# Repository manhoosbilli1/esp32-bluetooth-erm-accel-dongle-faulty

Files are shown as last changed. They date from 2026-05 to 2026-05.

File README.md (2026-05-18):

# daronjli_dongle_final_manufactured

ESP32 Bluetooth dongle with ERM haptic motor and accelerometer - FAULTY: wrong ORing circuit, used NMOS instead of PMOS

## At a Glance

- **Status**: Manufactured
- **Board size**: 23.26 x 28.39 mm
- **Layers**: 4
- **Components**: 56
- **Key ICs**:
  - U1: MCP73831-2-MC
  - U2: CP2102N-Axx-xQFN24
  - U3: LIS3DH
  - U4: DRV2605LDGS
  - U5: SY8089AAAC
  - U6: ESP32-WROOM-32E

## Schematic

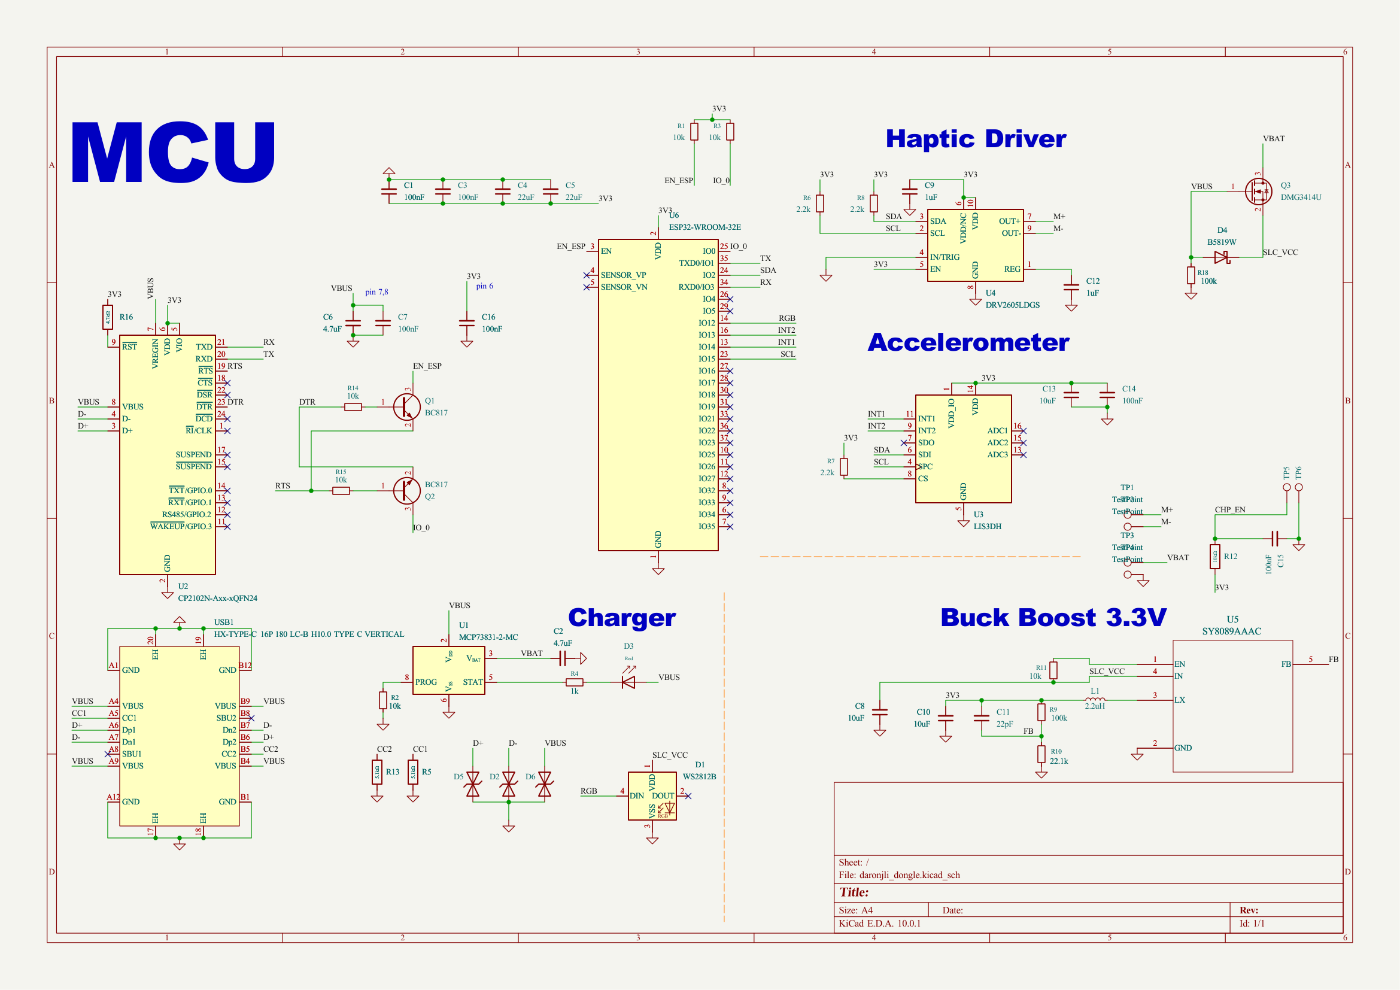
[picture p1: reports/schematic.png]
Schematic


Full PDF: [reports/schematic.pdf](reports/schematic.pdf)

## Component Roles

- **ESP32-WROVER-E** - main MCU with Bluetooth; firmware runs here
- **DRV2605LDGS** - haptic motor driver (configured for ERM motor) for tactile feedback
- **LIS3DH** - 3-axis accelerometer for orientation / motion detection
- **CP2102N** - USB-to-UART bridge for firmware programming
- **TPS63020** - buck-boost regulator (stable 3.3 V from a swinging LiPo)
- **MCP73871** - LiPo charger with PowerPath (USB vs battery source switching)
- **MAX17048** - I2C fuel gauge for battery percentage

## Known fault

This manufactured revision has a **broken OR-ing / PowerPath circuit**: the design used an N-channel MOSFET where a P-channel MOSFET was required. Result: source switching between USB and battery does not work correctly. Use the active [daronjli-dongle](https://github.com/manhoosbilli1/daronjli-dongle) repo for the fix.

## PCB

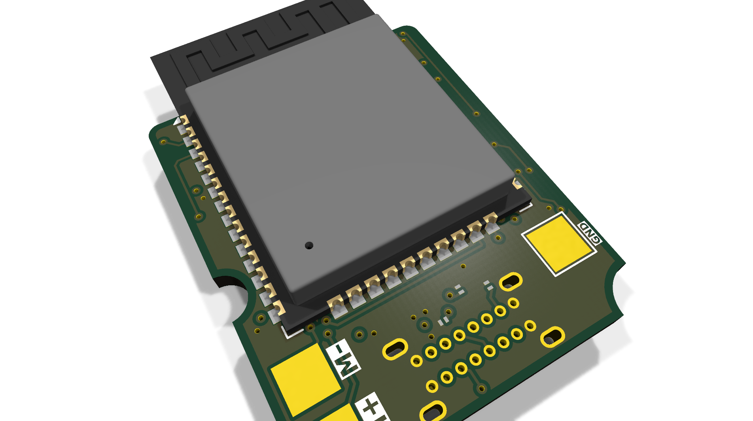
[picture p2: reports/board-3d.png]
3D top


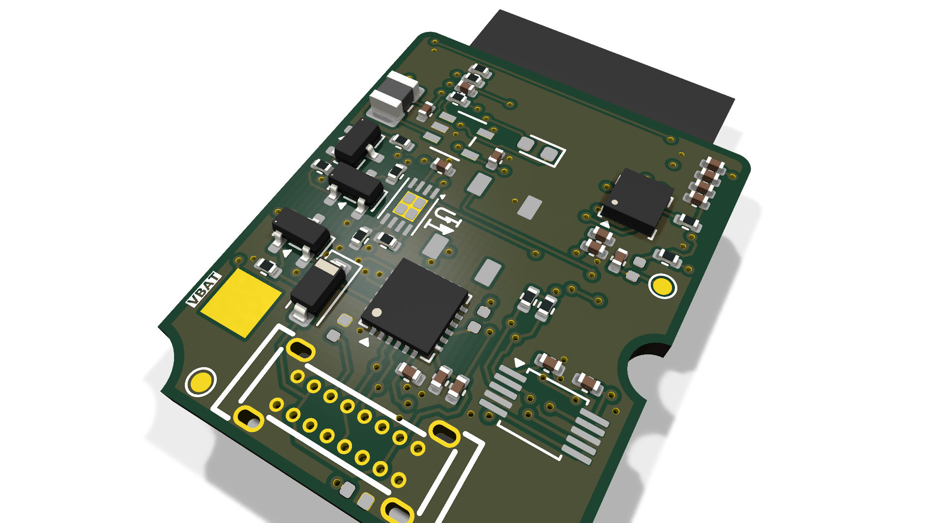
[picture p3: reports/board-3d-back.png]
3D bottom


**Top copper**

PCB top

**Bottom copper**

PCB bottom

## Bill of Materials

| Refs | Value | Footprint | Qty | MPN | LCSC |
|---|---|---|----:|-----|---|
| C1,C3,C7,C14-C16 | 100nF | Capacitor_SMD:C_0402_1005Metric | 6 |  |  |
| C2,C6 | 4.7uF | Capacitor_SMD:C_0402_1005Metric | 2 |  | [C307423](https://www.lcsc.com/product-detail/_C307423.html) |
| C4,C5 | 22uF | Capacitor_SMD:C_0402_1005Metric | 2 |  |  |
| C8,C10,C13 | 10uF | Capacitor_SMD:C_0402_1005Metric | 3 |  |  |
| C9,C12 | 1uF | Capacitor_SMD:C_0402_1005Metric | 2 |  |  |
| C11 | 22pF | Capacitor_SMD:C_0402_1005Metric | 1 |  |  |
| D1 | WS2812B | PCM_JLCPCB:LED_WS2812B_PLCC4_5.0x5.0mm_P3.2mm | 1 |  | [C22461793](https://www.lcsc.com/product-detail/_C22461793.html) |
| D2,D5,D6 | H5VL06B | PCM_JLCPCB:D_DFN0603-2L | 3 |  | [C7420373](https://www.lcsc.com/product-detail/_C7420373.html) |
| D3 | Red | PCM_JLCPCB:D_0603 | 1 |  | [C2286](https://www.lcsc.com/product-detail/_C2286.html) |
| D4 | B5819W | Diode_SMD:D_SOD-123 | 1 |  |  |
| L1 | 2.2uH | Inductor_SMD:L_1008_2520Metric_Pad1.43x2.20mm_HandSolder | 1 |  |  |
| Q1,Q2 | BC817 | Package_TO_SOT_SMD:SOT-23 | 2 |  |  |
| Q3 | DMG3414U | Package_TO_SOT_SMD:SOT-23 | 1 |  |  |
| R1-R3,R11,R14,R15 | 10k | Resistor_SMD:R_0402_1005Metric | 6 |  | [C60490](https://www.lcsc.com/product-detail/_C60490.html) |
| R4 | 1k | Resistor_SMD:R_0402_1005Metric | 1 |  | [C106235](https://www.lcsc.com/product-detail/_C106235.html) |
| R5,R13 | 5.1kΩ | PCM_JLCPCB:R_0402 | 2 |  | [C25905](https://www.lcsc.com/product-detail/_C25905.html) |
| R6-R8 | 2.2k | Resistor_SMD:R_0402_1005Metric | 3 |  |  |
| R9,R18 | 100k | Resistor_SMD:R_0402_1005Metric | 2 |  |  |
| R10 | 22.1k | Resistor_SMD:R_0402_1005Metric | 1 |  | [C43473](https://www.lcsc.com/product-detail/_C43473.html) |
| R12 | 10kΩ | PCM_JLCPCB:R_0402 | 1 |  | [C25744](https://www.lcsc.com/product-detail/_C25744.html) |
| R16 | 4.7kΩ | PCM_JLCPCB:R_0402 | 1 |  | [C25900](https://www.lcsc.com/product-detail/_C25900.html) |
| TP1-TP4 | TestPoint | TestPoint:TestPoint_Pad_3.0x3.0mm | 4 |  |  |
| TP5,TP6 | TestPoint | TestPoint:TestPoint_Pad_D1.0mm | 2 |  |  |
| U1 | MCP73831-2-MC | Package_DFN_QFN:DFN-8-1EP_3x2mm_P0.5mm_EP1.7x1.4mm | 1 |  | [C150772](https://www.lcsc.com/product-detail/_C150772.html) |
| U2 | CP2102N-Axx-xQFN24 | Package_DFN_QFN:QFN-24-1EP_4x4mm_P0.5mm_EP2.6x2.6mm | 1 |  | [C969151](https://www.lcsc.com/product-detail/_C969151.html) |
| U3 | LIS3DH | Package_LGA:LGA-16_3x3mm_P0.5mm_LayoutBorder3x5y | 1 |  |  |
| U4 | DRV2605LDGS | Package_SO:VSSOP-10_3x3mm_P0.5mm | 1 |  |  |
| U5 | SY8089AAAC | footprints:SY8089AAAC_SGY | 1 |  |  |
| U6 | ESP32-WROOM-32E | RF_Module:ESP32-WROOM-32D | 1 |  | [C701343](https://www.lcsc.com/product-detail/_C701343.html) |
| USB1 | HX-TYPE-C 16P 180 LC-B H10.0 TYPE C VERTICAL | :USB-C-TH_HX-TYPE-C-16P-180-LC-BH10.0-TYPE-C-VERTICAL | 1 |  |  |

_17 of 30 line items don't have an LCSC code in the schematic - search [LCSC](https://www.lcsc.com/) or [JLC parts search](https://jlcsearch.tscircuit.com/) by MPN or footprint when sourcing._

## Files

- `daronjli_dongle.kicad_pro` - KiCad project
- `daronjli_dongle.kicad_sch` - schematic source
- `daronjli_dongle.kicad_pcb` - PCB layout source
- `reports/schematic.pdf` - full schematic (printable)
- `reports/bom.csv` - bill of materials
- `reports/pcb-top.svg`, `reports/pcb-bottom.svg` - copper artwork
- `reports/board-stats.json` - KiCad-generated board statistics

---

_Renders and metadata auto-generated by `Backup-KiCadProject.ps1` using KiCad 10.0._

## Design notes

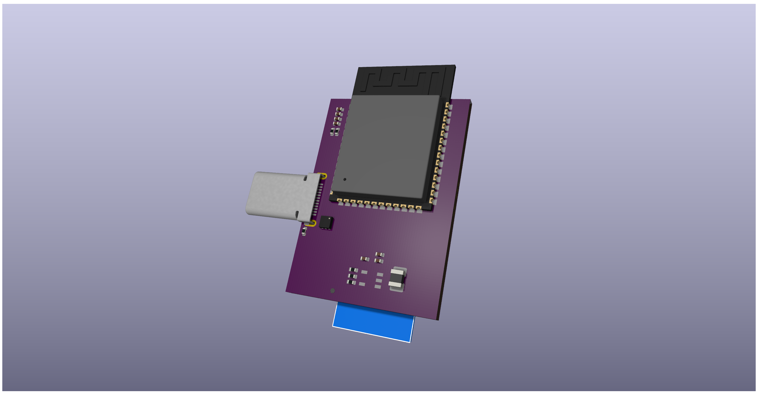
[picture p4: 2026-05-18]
daronjli_dongle.png

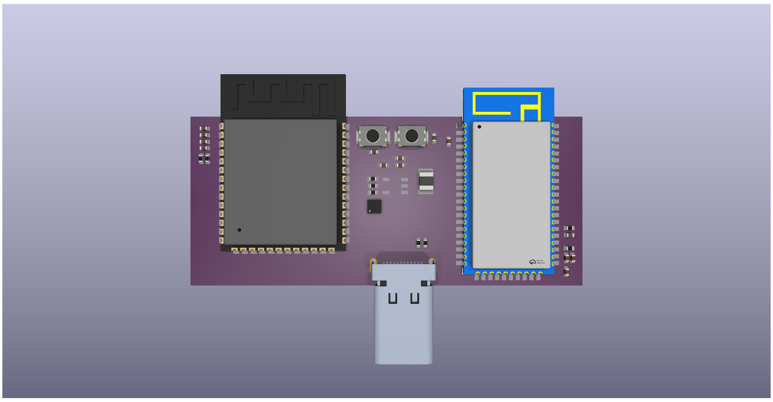
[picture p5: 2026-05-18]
daronjli_dongle_draft1_placement.png

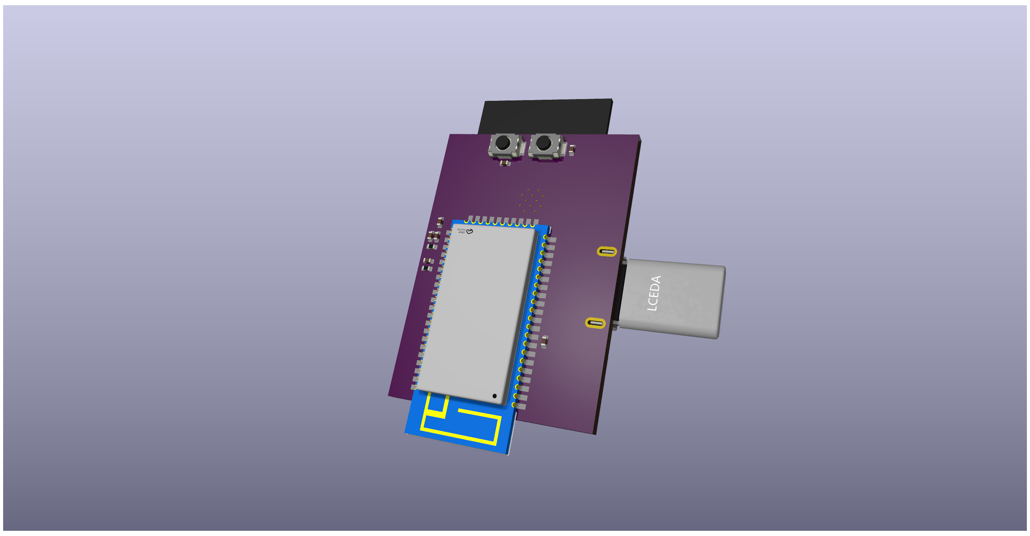
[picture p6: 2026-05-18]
daronjli_dongle_back.png

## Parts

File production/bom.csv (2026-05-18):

Designator | Footprint | Quantity | Value | LCSC Part #
C1, C14, C15, C16, C3, C7 | 0402 | 6 | 100nF
C10, C13, C8 | 0402 | 3 | 10uF
C11 | 0402 | 1 | 22pF
C12, C9 | 0402 | 2 | 1uF
C2, C6 | 0402 | 2 | 4.7uF | C307423
C4, C5 | 0402 | 2 | 22uF
D1 | LED_WS2812B_PLCC4_5.0x5.0mm_P3.2mm | 1 | WS2812B | C22461793
D2, D5, D6 | D_DFN0603-2L | 3 | H5VL06B | C7420373
D3 | D_0603 | 1 | Red | C2286
D4 | D_SOD-123 | 1 | B5819W
L1 | 1008 | 1 | 2.2uH
Q1, Q2 | SOT-23 | 2 | BC817
Q3 | SOT-23 | 1 | DMG3414U
R1, R11, R14, R15, R3 | 0402 | 5 | 10k
R10 | 0402 | 1 | 22.1k | C43473
R12 | R_0402 | 1 | 10kΩ | C25744
R13, R5 | R_0402 | 2 | 5.1kΩ | C25905
R16 | R_0402 | 1 | 4.7kΩ | C25900
R18, R9 | 0402 | 2 | 100k
R2 | 0402 | 1 | 10k | C60490
R4 | 0402 | 1 | 1k | C106235
R6, R7, R8 | 0402 | 3 | 2.2k
TP1, TP2, TP3, TP4 | TestPoint_Pad_3.0x3.0mm | 4 | TestPoint
TP5, TP6 | TestPoint_Pad_D1.0mm | 2 | TestPoint
U1 | DFN-8-1EP_3x2mm_P0.5mm_EP1.7x1.4mm | 1 | MCP73831-2-MC | C150772
U2 | QFN-24-1EP_4x4mm_P0.5mm_EP2.6x2.6mm | 1 | CP2102N-Axx-xQFN24 | C969151
U3 | LGA-16_3x3mm_P0.5mm_LayoutBorder3x5y | 1 | LIS3DH
U4 | VSSOP-10_3x3mm_P0.5mm | 1 | DRV2605LDGS
U5 | SY8089AAAC_SGY | 1 | SY8089AAAC
U6 | ESP32-WROOM-32D | 1 | ESP32-WROOM-32E | C701343
USB1 | USB-C-TH_HX-TYPE-C-16P-180-LC-BH10.0-TYPE-C-VERTICAL | 1 | HX-TYPE-C 16P 180 LC-B H10.0 TYPE C VERTICAL | C49261584

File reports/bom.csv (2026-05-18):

Refs | Value | Footprint | Qty | Description | Mfr | MPN | LCSC
C1,C3,C7,C14-C16 | 100nF | Capacitor_SMD:C_0402_1005Metric | 6 | Unpolarized capacitor, small symbol
C2,C6 | 4.7uF | Capacitor_SMD:C_0402_1005Metric | 2 | Unpolarized capacitor, small symbol |  |  | C307423
C4,C5 | 22uF | Capacitor_SMD:C_0402_1005Metric | 2 | Unpolarized capacitor, small symbol
C8,C10,C13 | 10uF | Capacitor_SMD:C_0402_1005Metric | 3 | Unpolarized capacitor, small symbol
C9,C12 | 1uF | Capacitor_SMD:C_0402_1005Metric | 2 | Unpolarized capacitor, small symbol
C11 | 22pF | Capacitor_SMD:C_0402_1005Metric | 1 | Unpolarized capacitor, small symbol
D1 | WS2812B | PCM_JLCPCB:LED_WS2812B_PLCC4_5.0x5.0mm_P3.2mm | 1 | RGB LED with integrated controller |  |  | C22461793
D2,D5,D6 | H5VL06B | PCM_JLCPCB:D_DFN0603-2L | 3 | 8A 10V 80W 5.6V Bidirectional 5V DFN0603-2L ESD and Surge Protection (TVS/ESD) ROHS | hongjiacheng |  | C7420373
D3 | Red | PCM_JLCPCB:D_0603 | 1 | -40°C~+85°C Red 0603 LED Indication - Discrete ROHS | Hubei KENTO Elec |  | C2286
D4 | B5819W | Diode_SMD:D_SOD-123 | 1 | Schottky diode
L1 | 2.2uH | Inductor_SMD:L_1008_2520Metric_Pad1.43x2.20mm_HandSolder | 1 | Inductor, small symbol
Q1,Q2 | BC817 | Package_TO_SOT_SMD:SOT-23 | 2 | 0.8A Ic, 45V Vce, NPN Transistor, SOT-23
Q3 | DMG3414U | Package_TO_SOT_SMD:SOT-23 | 1 | 4.2A Id, 20V Vds, N-Channel MOSFET, SOT-23
R1-R3,R11,R14,R15 | 10k | Resistor_SMD:R_0402_1005Metric | 6 | Resistor, small symbol |  |  | C60490
R4 | 1k | Resistor_SMD:R_0402_1005Metric | 1 | Resistor, small symbol |  |  | C106235
R5,R13 | 5.1kΩ | PCM_JLCPCB:R_0402 | 2 | 62.5mW Thick Film Resistors 50V ±100ppm/°C ±1% 5.1kΩ 0402 Chip Resistor - Surface Mount ROHS | UNI-ROYAL(Uniroyal Elec) |  | C25905
R6-R8 | 2.2k | Resistor_SMD:R_0402_1005Metric | 3 | Resistor, small symbol
R9,R18 | 100k | Resistor_SMD:R_0402_1005Metric | 2 | Resistor, small symbol
R10 | 22.1k | Resistor_SMD:R_0402_1005Metric | 1 | Resistor, small symbol |  |  | C43473
R12 | 10kΩ | PCM_JLCPCB:R_0402 | 1 | 62.5mW Thick Film Resistors 50V ±100ppm/°C ±1% 10kΩ 0402 Chip Resistor - Surface Mount ROHS | UNI-ROYAL(Uniroyal Elec) |  | C25744
R16 | 4.7kΩ | PCM_JLCPCB:R_0402 | 1 | 62.5mW Thick Film Resistors 50V ±100ppm/°C ±1% 4.7kΩ 0402 Chip Resistor - Surface Mount ROHS | UNI-ROYAL(Uniroyal Elec) |  | C25900
TP1-TP4 | TestPoint | TestPoint:TestPoint_Pad_3.0x3.0mm | 4 | test point
TP5,TP6 | TestPoint | TestPoint:TestPoint_Pad_D1.0mm | 2 | test point
U1 | MCP73831-2-MC | Package_DFN_QFN:DFN-8-1EP_3x2mm_P0.5mm_EP1.7x1.4mm | 1 | Single cell, Li-Ion/Li-Po charge management controller, 4.20V, Tri-State Status Output, in DFN-8 package |  |  | C150772
U2 | CP2102N-Axx-xQFN24 | Package_DFN_QFN:QFN-24-1EP_4x4mm_P0.5mm_EP2.6x2.6mm | 1 | USB to UART master bridge, QFN-24 |  |  | C969151
U3 | LIS3DH | Package_LGA:LGA-16_3x3mm_P0.5mm_LayoutBorder3x5y | 1 | 3-Axis Accelerometer, 2/4/8/16g range, I2C/SPI interface, LGA-16
U4 | DRV2605LDGS | Package_SO:VSSOP-10_3x3mm_P0.5mm | 1 | Haptic driver for LRAs and ERMs with effect library, 2-5.2V, VSSOP-10
U5 | SY8089AAAC | footprints:SY8089AAAC_SGY | 1
U6 | ESP32-WROOM-32E | RF_Module:ESP32-WROOM-32D | 1 | RF Module, ESP32-D0WD-V3 SoC, without PSRAM, Wi-Fi 802.11b/g/n, Bluetooth, BLE, 32-bit, 2.7-3.6V, onboard antenna, SMD |  |  | C701343
USB1 | HX-TYPE-C 16P 180 LC-B H10.0 TYPE C VERTICAL | :USB-C-TH_HX-TYPE-C-16P-180-LC-BH10.0-TYPE-C-VERTICAL | 1

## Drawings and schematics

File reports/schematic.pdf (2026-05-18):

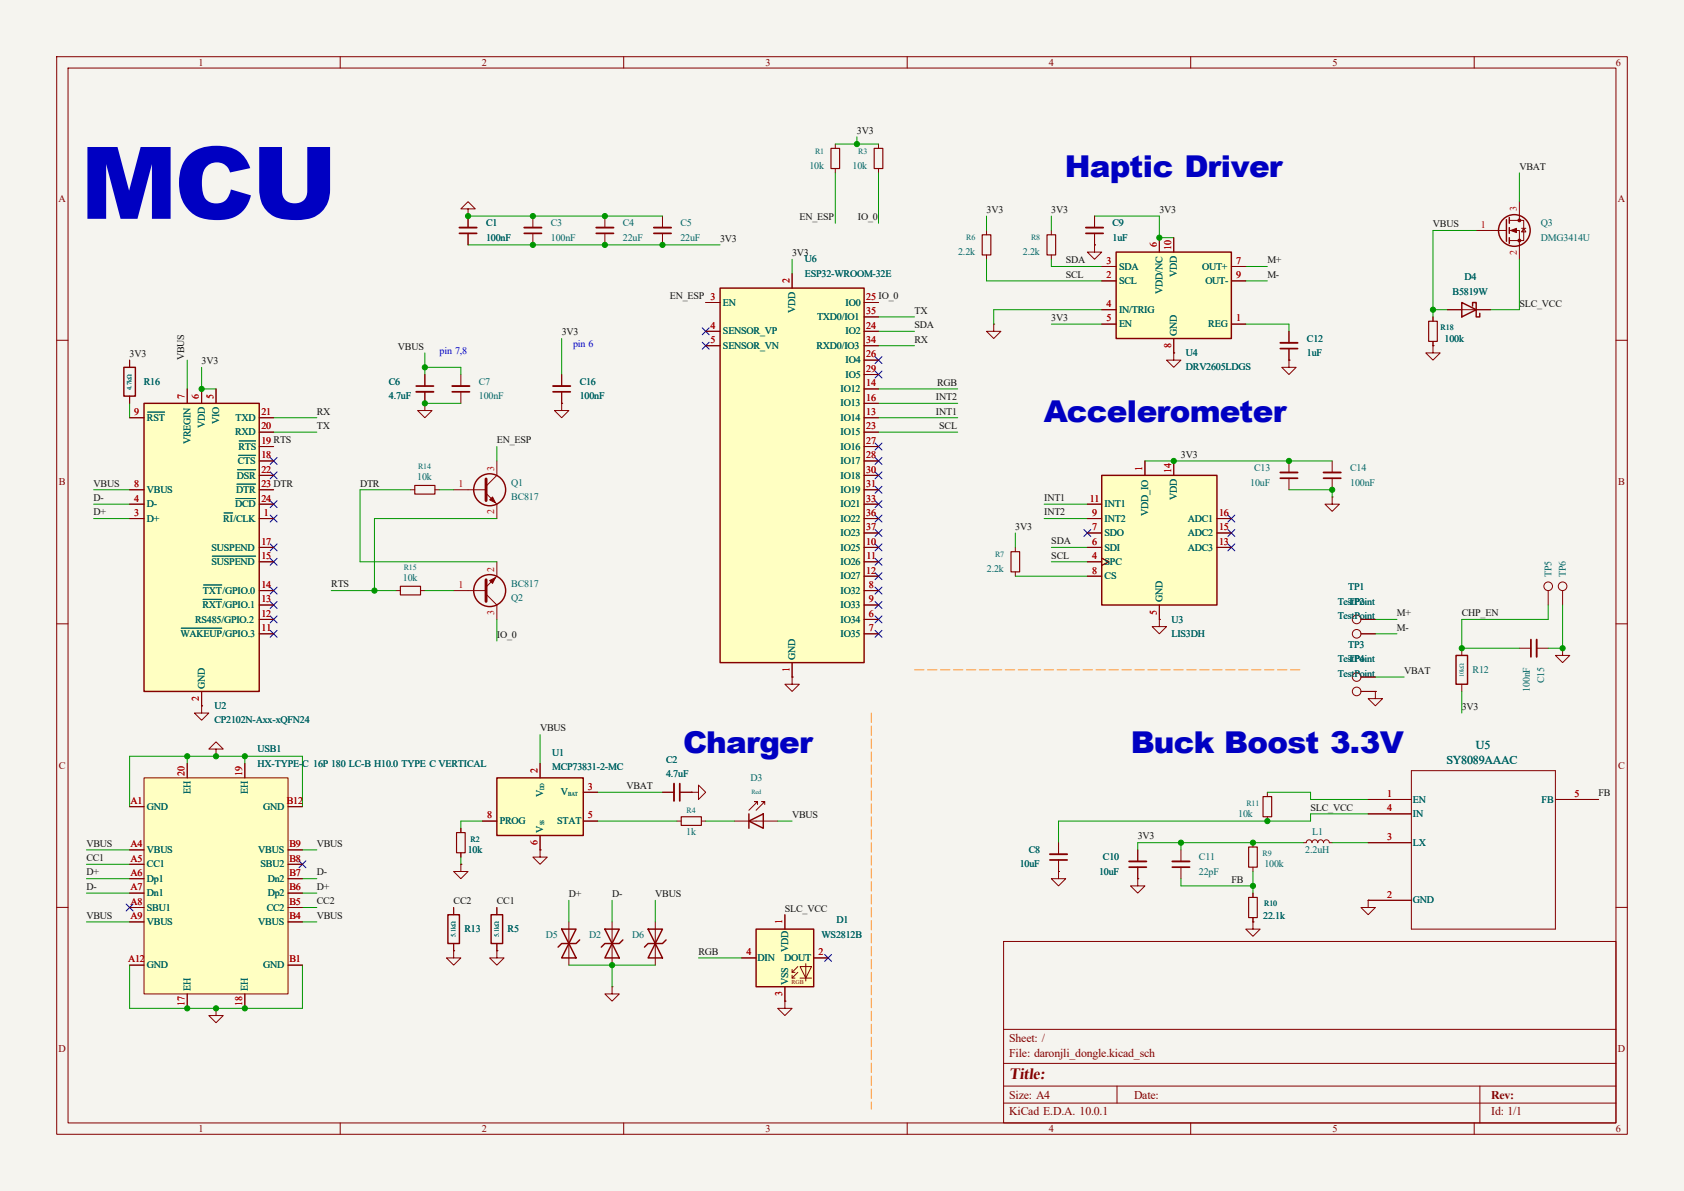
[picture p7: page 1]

8 OUT- VDD 9 10 U4 DRV2605LDGS EH 17 EH 18 EH 19 EH 20 GND A1 VBUS A4 CC1 A5 Dp1 A6 Dn1 A7 SBU1 A8 VBUS A9 GND A12 GND B1 VBUS B4 CC2 B5 Dp2 B6 Dn2 B7 SBU2 B8 VBUS B9 GND B12 USB1 HX-TYPE-C 16P 180 LC-B H10.0 TYPE C VERTICAL R13 5.1kΩ R2 10k R7 2.2k VDD_IO

7 VBUS 8 RST 9 WAKEUP/GPIO.3 11 RS485/GPIO.2 12 RXT/GPIO.1 13 TXT/GPIO.0 14 SUSPEND 15 SUSPEND 17 CTS 18 RTS 19 RXD 20 TXD 21 DSR 22 DTR 23 DCD 24 R16 4.7kΩ D1 WS2812B VDD

7 VBUS 8 RST 9 WAKEUP/GPIO.3 11 RS485/GPIO.2 12 RXT/GPIO.1 13 TXT/GPIO.0 14 SUSPEND 15 SUSPEND 17 CTS 18 RTS 19 RXD 20 TXD 21 DSR 22 DTR 23 DCD 24 U2 CP2102N-Axx-xQFN24 C6

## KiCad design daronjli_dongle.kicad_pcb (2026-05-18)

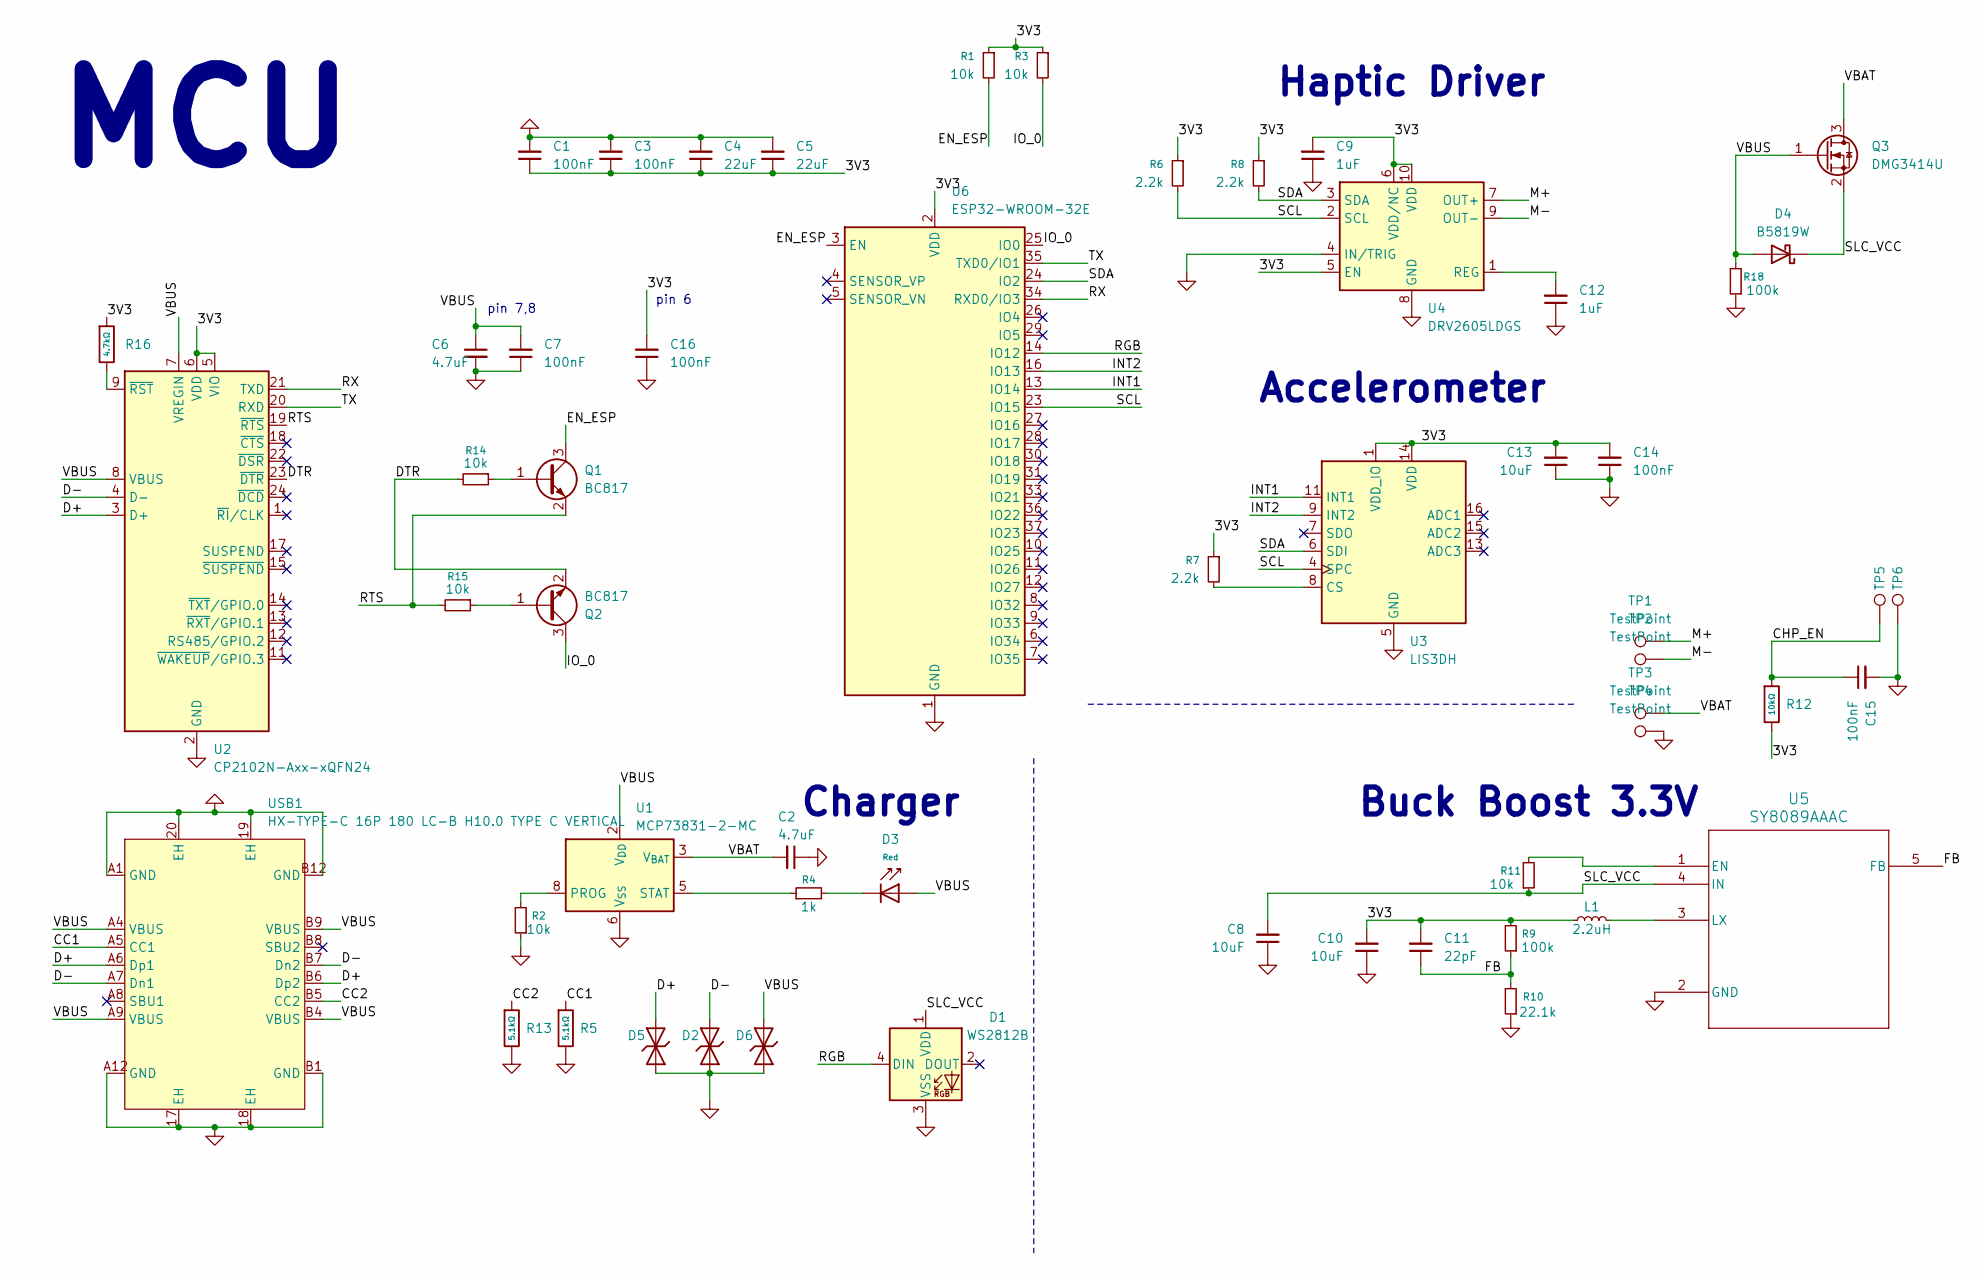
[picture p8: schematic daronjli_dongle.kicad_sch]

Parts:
C1, C3, C7, C14, C15, C16: 100nF; C_0402_1005Metric
C2, C6: 4.7uF; C_0402_1005Metric; LCSC C307423
C4, C5: 22uF; C_0402_1005Metric
C8, C10, C13: 10uF; C_0402_1005Metric
C9, C12: 1uF; C_0402_1005Metric
C11: 22pF; C_0402_1005Metric
D1: WS2812B; LED_WS2812B_PLCC4_5.0x5.0mm_P3.2mm; LCSC C22461793
D2, D5, D6: H5VL06B; D_DFN0603-2L; Clamping Voltage@Ipp 10V; Breakdown Voltage (VBR) 5.6V; Part H5VL06B; LCSC C7420373
D3: Red; D_0603; Part KT-0603R; LCSC C2286
D4: B5819W; D_SOD-123
L1: 2.2uH; L_1008_2520Metric_Pad1.43x2.20mm_HandSolder
Q1, Q2: BC817; SOT-23
Q3: DMG3414U; SOT-23
R1, R3, R11, R14, R15: 10k; R_0402_1005Metric
R2: 10k; R_0402_1005Metric; LCSC C60490
R4: 1k; R_0402_1005Metric; LCSC C106235
R5, R13: 5.1kΩ; R_0402; Overload Voltage (Max) 50V; Tolerance ±1%; Part 0402WGF5101TCE; LCSC C25905
R6, R7, R8: 2.2k; R_0402_1005Metric
R9, R18: 100k; R_0402_1005Metric
R10: 22.1k; R_0402_1005Metric; LCSC C43473
R12: 10kΩ; R_0402; Overload Voltage (Max) 50V; Tolerance ±1%; Part 0402WGF1002TCE; LCSC C25744
R16: 4.7kΩ; R_0402; Overload Voltage (Max) 50V; Tolerance ±1%; Part 0402WGF4701TCE; LCSC C25900
TP1, TP2, TP3, TP4: TestPoint; TestPoint_Pad_3.0x3.0mm
TP5, TP6: TestPoint; TestPoint_Pad_D1.0mm
U1: MCP73831-2-MC; DFN-8-1EP_3x2mm_P0.5mm_EP1.7x1.4mm; LCSC C150772
U2: CP2102N-Axx-xQFN24; QFN-24-1EP_4x4mm_P0.5mm_EP2.6x2.6mm; LCSC C969151
U3: LIS3DH; LGA-16_3x3mm_P0.5mm_LayoutBorder3x5y
U4: DRV2605LDGS; VSSOP-10_3x3mm_P0.5mm
U5: SY8089AAAC; SY8089AAAC_SGY
U6: ESP32-WROOM-32E; ESP32-WROOM-32D; LCSC C701343
USB1: HX-TYPE-C 16P 180 LC-B H10.0 TYPE C VERTICAL; USB-C-TH_HX-TYPE-C-16P-180-LC-BH10.0-TYPE-C-VERTICAL; LCSC Part C49261584

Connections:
/3V3: C1.1, C3.1, C4.1, C5.1, C9.2, C10.2, C11.2, C13.2, C14.2, C16.2, L1.1, R1.1, R3.1, R6.1, R7.1, R8.1, R9.2, R12.2, R16.1, U2.5 (VIO), U2.6 (VDD), U3.1 (VDD_IO), U3.14 (VDD), U4.5 (EN), U4.6 (VDD/NC), U4.10 (VDD), U6.2 (VDD)
/CC1: R5.1, USB1.A5 (CC1)
/CC2: R13.1, USB1.B5 (CC2)
/CHP_EN: C15.1, R12.1, TP5.1
/D+: D5.2, U2.3 (D+), USB1.A6 (Dp1), USB1.B6 (Dp2)
/D-: D2.2, U2.4 (D-), USB1.A7 (Dn1), USB1.B7 (Dn2)
/DTR: Q2.2 (E), R14.2, U2.23 (~DTR)
/EN_ESP: Q1.3 (C), R1.2, U6.3 (EN)
/FB: C11.1, R9.1, R10.2, U5.5 (FB)
/INT1: U3.11 (INT1), U6.13 (IO14)
/INT2: U3.9 (INT2), U6.16 (IO13)
/IO_0: Q2.3 (C), R3.2, U6.25 (IO0)
/M+: TP1.1, U4.7 (OUT+)
/M-: TP2.1, U4.9 (OUT-)
/RGB: D1.4 (DIN), U6.14 (IO12)
/RTS: Q1.2 (E), R15.2, U2.19 (~RTS)
/RX: U2.21 (TXD), U6.34 (RXD0/IO3)
/SCL: R6.2, U3.4 (SPC), U4.2 (SCL), U6.23 (IO15)
/SDA: R8.2, U3.6 (SDI), U4.3 (SDA), U6.24 (IO2)
/SLC_VCC: C8.2, D1.1 (VDD), D4.1 (K), Q3.2 (S), R11.1, U5.4 (IN)
/TX: U2.20 (RXD), U6.35 (TXD0/IO1)
/VBAT: C2.2, Q3.3 (D), TP3.1, U1.3 (V_{BAT}), U1.4 (V_{BAT})
/VBUS: C6.1, C7.2, D3.2, D4.2 (A), D6.2, Q3.1 (G), R18.2, U1.1 (V_{DD}), U1.2 (V_{DD}), U2.7 (VREGIN), U2.8 (VBUS), USB1.A4 (VBUS), USB1.A9 (VBUS), USB1.B4 (VBUS), USB1.B9 (VBUS)
GND: C1.2, C2.1, C3.2, C4.2, C5.2, C6.2, C7.1, C8.1, C9.1, C10.1, C12.1, C13.1, C14.1, C15.2, C16.1, D1.3 (VSS), D2.1, D5.1, D6.1, R2.1, R5.2, R10.1, R13.2, R18.1, TP4.1, TP6.1, U1.6 (V_{SS}), U2.2 (GND), U2.25 (GND), U3.5 (GND), U3.10 (GND), U3.12 (GND), U4.4 (IN/TRIG), U4.8 (GND), U5.2 (GND), U6.1 (GND), U6.15 (GND), U6.38 (GND), U6.39 (GND), USB1.17 (EH), USB1.18 (EH), USB1.19 (EH), USB1.20 (EH), USB1.A1 (GND), USB1.A12 (GND), USB1.B1 (GND), USB1.B12 (GND)
unnamed: D3.1, R4.2
unnamed: Q1.1 (B), R14.1
unnamed: Q2.1 (B), R15.1
unnamed: R2.2, U1.8 (PROG)
unnamed: R4.1, U1.5 (STAT)
unnamed: R16.2, U2.9 (~RST)
unnamed: R7.2, U3.8 (CS)
unnamed: C12.2, U4.1 (REG)
unnamed: R11.2, U5.1 (EN)
unnamed: L1.2, U5.3 (LX)

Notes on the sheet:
pin 7,8
pin 6
MCU
Buck Boost 3.3V
Haptic Driver
Accelerometer
Charger

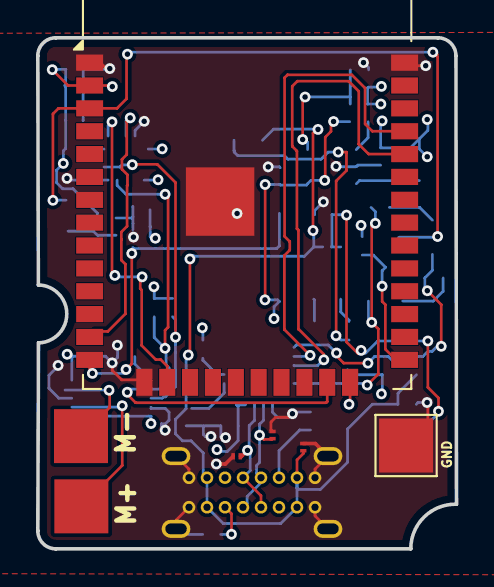
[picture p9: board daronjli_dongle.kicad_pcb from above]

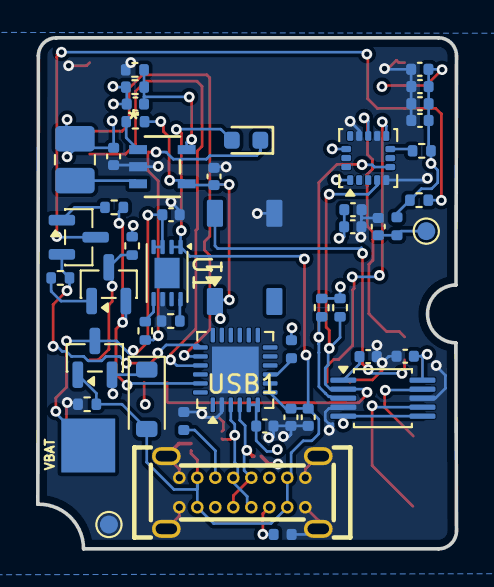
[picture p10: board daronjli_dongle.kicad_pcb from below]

Board: 4 copper layers, 23.3 x 28.4 mm, 56 parts (49 on the bottom side), 34 nets.

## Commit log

2026-05-18 Initial backup: schematic, PCB, renders, BOM
    [bom.csv, daronjli_dongle.kicad_pcb, daronjli_dongle.kicad_sch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]
2026-05-18 Enrich README: schematic PNG, component roles, BOM table
